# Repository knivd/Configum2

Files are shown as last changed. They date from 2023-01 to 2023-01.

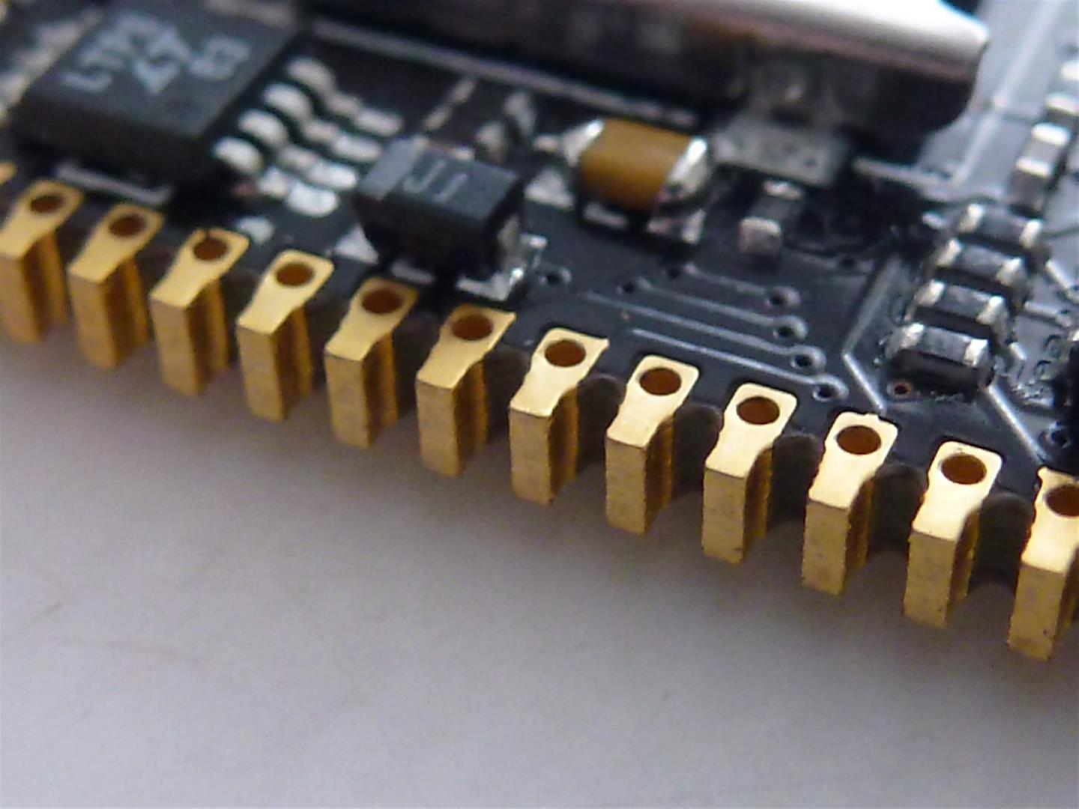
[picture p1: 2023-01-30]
hardware/Pin Finishing.JPG

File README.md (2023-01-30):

# Configum2
Embedded FPGA module in PLCC84 format

This tiny 30x30mm module fits into standard PLCC84 socket and offers:
Artix-7 FPGA, 64Mb configuration flash, 1Gb DDR3, 16Gb eMMC, ESP32 dual-core controller, 64Mb external firmware flash, USB host, 4-channel motor controller, 24MHz oscillator, dual power supply that provides 1.8V and 3.3V to external circuit with over 3A budget, on-board debug LEDs, differential ADC, up to 61 external I/O ports.
FPGA and ESP32 share most of the external pins and can work in parallel.
Configum-2 is ideal for ultra-dense high-end boards for robotics, AI, industrial, wearables, etc.

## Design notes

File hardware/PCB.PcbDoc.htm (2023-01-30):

Reporting Options

# File in Previous Format

Date | : | 31/12/2021
Time | : | 15:15:40
Filename | : | K:\Work\Past\Configum-2\hardware\PCB.PcbDoc

Version | Warning

This file was generated by an earlier version of the software

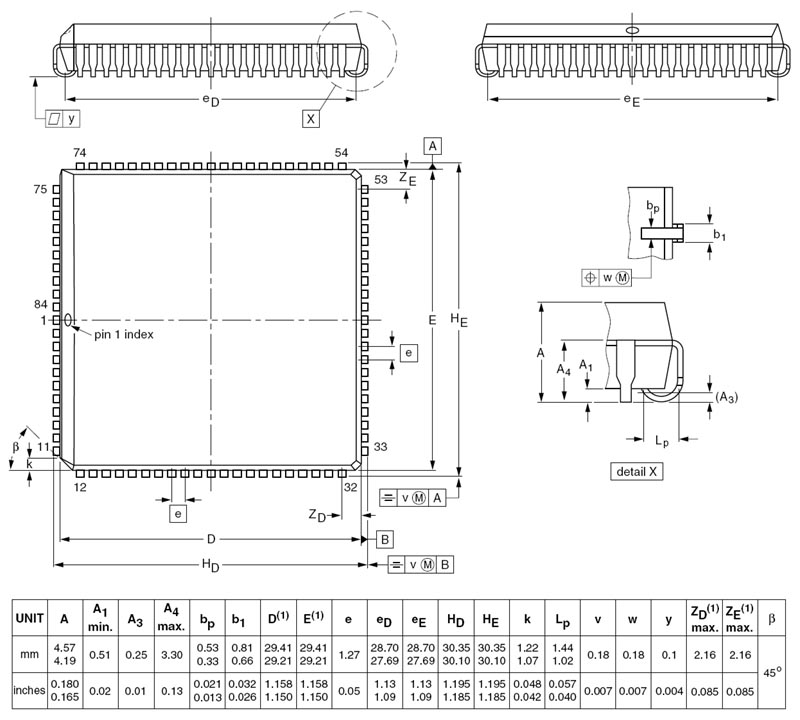
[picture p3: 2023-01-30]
docs/PLCC84.jpg

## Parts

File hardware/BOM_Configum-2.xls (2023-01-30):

Comment | Pattern | Quantity | Components | Vendor | Order Code | Vendor | Order Code | Vendor | Order Code | Description / Minimum Specification
1u | _0201 | 62 | C1, C2, C3, C4, C5, C6, C7, C8, C9, C10, C11, C12, C13, C14, C15, C16, C17, C18, C19, C20, C21, C22, C23, C24, C25, C26, C27, C28, C29, C30, C31, C32, C33, C34, C35, C36, C37, C38, C39, C40, C42, C43, C44, C45, C46, C47, C48, C49, C52, C56, C59, C62, C63, C74, C80, C102, C103, C104, C105, C107, C108, C109 | Any |  |  |  |  |  | Ceramic capacitor, X-type, 10%, 6V or higher
270p | _0201 | 2 | C100, C101 | Any |  |  |  |  |  | Ceramic capacitor, C0G/NP0, 5%, 6V or higher
100n | _0201 | 30 | C41, C50, C58, C61, C64, C65, C66, C67, C69, C70, C71, C72, C73, C75, C77, C78, C81, C83, C84, C86, C88, C89, C91, C92, C93, C94, C98, C106, C110, C112 | Any |  |  |  |  |  | Ceramic capacitor, X-type, 10%, 6V or higher
33n | _0201 | 1 | C51 | Any |  |  |  |  |  | Ceramic capacitor, X-type, 10%, 6V or higher
22u | _0805_CAP | 3 | C53, C54, C111 | Any |  |  |  |  |  | Ceramic capacitor, X-type, 10%, 16V or higher
47u | _0805_CAP | 4 | C55, C60, C68, C90 | Any |  |  |  |  |  | Ceramic capacitor, X-type, 10%, 6V or higher
2u2 | _0201 | 2 | C57, C99 | Any |  |  |  |  |  | Ceramic capacitor, X-type, 10%, 6V or higher
10n | _0201 | 3 | C76, C79, C95 | Any |  |  |  |  |  | Ceramic capacitor, X-type, 10%, 6V or higher
2p4 | _0201 | 1 | C82 | Any |  |  |  |  |  | Ceramic capacitor, C0G/NP0, 5%, 6V or higher
3n | _0201 | 1 | C85 | Any |  |  |  |  |  | Ceramic capacitor, X-type, 10%, 6V or higher
3p9 | _0201 | 1 | C87 | Any |  |  |  |  |  | Ceramic capacitor, C0G/NP0, 5%, 6V or higher
10u | _0603 | 2 | C96, C97 | Any |  |  |  |  |  | Ceramic capacitor, X-type, 10%, 6V or higher
2n7 | _0201 | 1 | L5 | Any |  |  |  |  |  | Inductor
1k | _0201 | 5 | R1, R3, R4, R7, R53 | Any |  |  |  |  |  | Resistor, 1%
12k | _0201 | 1 | R11 | Any |  |  |  |  |  | Resistor, 1%
27k | _0201 | 1 | R13 | Any |  |  |  |  |  | Resistor, 1%
90k9 | _0201 | 1 | R14 | Any |  |  |  |  |  | Resistor, 1%
30k1 | _0201 | 1 | R16 | Any |  |  |  |  |  | Resistor, 1%
47k5 | _0201 | 1 | R17 | Any |  |  |  |  |  | Resistor, 1%
20k | _0201 | 3 | R18, R33, R55 | Any |  |  |  |  |  | Resistor, 1%
240R | _0201 | 3 | R19, R20, R22 | Any |  |  |  |  |  | Resistor, 1%
4k7 | _0201 | 7 | R2, R5, R10, R12, R15, R30, R52 | Any |  |  |  |  |  | Resistor, 1%
13k3 | _0201 | 1 | R21 | Any |  |  |  |  |  | Resistor, 1%
47R | _0201 | 27 | R23, R24, R25, R26, R27, R28, R29, R31, R32, R34, R35, R36, R37, R38, R39, R40, R41, R42, R43, R44, R45, R46, R47, R48, R49, R50, R54 | Any |  |  |  |  |  | Resistor, 1%
330R | _0201 | 1 | R6 | Any |  |  |  |  |  | Resistor, 1%
2k4 | _0201 | 1 | R8 | Any |  |  |  |  |  | Resistor, 1%
24R9 | _0201 | 1 | R9 | Any |  |  |  |  |  | Resistor, 1%
DNF | _0201 | 1 | R51 |  |  |  |  |  |  | Resistor, 1%
60R@100MHz | _0201 | 4 | L1, L2, L3, L4 | Aliexpress | 32761245784 | Mouser | 963-BK0603HM600-T | Digikey | 535-12206-1-ND | Inductor
0402R | _0402+ | 1 | LED1 | Aliexpress | 32404466579 | Mouser | 604-APHHS1005SURCK | Digikey | 1516-1217-1-ND | Light Emitting Diode
0402Y | _0402+ | 1 | LED2 | Aliexpress | 32688253887 | Mouser | 604-APHHS1005SYCK | Digikey | 1516-1219-1-ND | Light Emitting Diode
0402G | _0402+ | 1 | LED3 | Aliexpress | 32688370228 | Mouser | 604-APHHS1005CGCK | Digikey | 1516-1216-1-ND | Light Emitting Diode
0402B | _0402+ | 1 | LED4 | Aliexpress | 32403229689 | Mouser | 604-APHHS1005QBCD | Digikey | 1516-1215-1-ND | Light Emitting Diode
XC7A100T-2CSG324C | CSG324 | 1 | U1 | Aliexpress | 32735014145 | Avnet | XC7A100T-2CSG324I | Digikey | 122-1881-ND | Artix-7 FPGA, 210 User I/Os, 0 GTP, 324-Ball BGA, Speed Grade 2, Commercial Grade, Pb-Free
LV8411GR | QFN40P300X300X80_HS-25L | 1 | U11 | Aliexpress | 32575151815 | Mouser | 863-LV8411GR-TE-L-E | Digikey | 869-1285-1-ND | 4-channel single chip motor driver IC
IS25LQ032B-JTLA | SON80P300X60_HS-9L | 2 | U2, U10 | Arrow | MX25L3233FZBI-08G-TR | Arrow | N25Q032A13EF440F | Vertical | N25Q032A13EF440F | Standard 8-pin SPI flash memory
DSC1033DI2-024.0000 | Osc 25x20 (4) | 1 | U3 | Vertical | DSC1033DI2-024.0000 | Mouser | 579-1033DI20240000 | Digikey | DSC1033DI2-024.0000-ND | 32kHz –100MHz CMEMS Oscillator
MIC94093YMT | DFN65P120x120-4 | 2 | U4, U12 | Aliexpress | 32565684921 | Mouser | 998-MIC94093YMTTR | Digikey | 576-3491-1-ND | High-side load switch for consumer applications
ADS7041IRUG | X2QFN50P150X150-8 | 1 | U5 | Aliexpress | 32400654595 | Mouser | 595-ADS7041IRUGR | Digikey | 296-38606-1-ND | Ultra-Low Power, Ultra-Small Size, 10-Bit, 1-MSPS, SAR ADC
USB3300-EZK | QFN50P500X500-32V5N | 1 | U6 | Aliexpress | 32639284916 | Mouser | 886-USB3300-EZK | Digikey | USB3300-EZK-CT-ND | Hi-Speed USB Host, Device or OTG PHY with ULPI Low Pin Interface
AS4C512M16D3L-12BCN | BGA96C80P9X16_900X1400X120 | 1 | U7 | Aliexpress | 32761447879 | Mouser | 913-512M16D3L12BCN | Digikey | 1450-1271-ND | DDR3L RAM 8Gb (512Mx16)
ESP32-D0WDQ6 | QFN40P600X600X90-49N-S470 | 1 | U8 |  |  |  |  |  |  | WiFi, BT4.2, 2xCPU integrated solution
eMMC-153 | BGA153C50P14X14_1150X1300X90 | 1 | U9 | Aliexpress | 32367008543 | Mouser | 757-THGBMHG6C1LBAIL | Digikey | THGBMHG6C1LBAIL-ND | eMMC memory
LTM4643EV#PBF | LGA77C127P7X11_900X1500X182 | 1 | UM1 | Linear | LTM4643EV#PBF |  |  |  |  | Ultrathin Quad Module Regulator with Configurable 3A Output Array

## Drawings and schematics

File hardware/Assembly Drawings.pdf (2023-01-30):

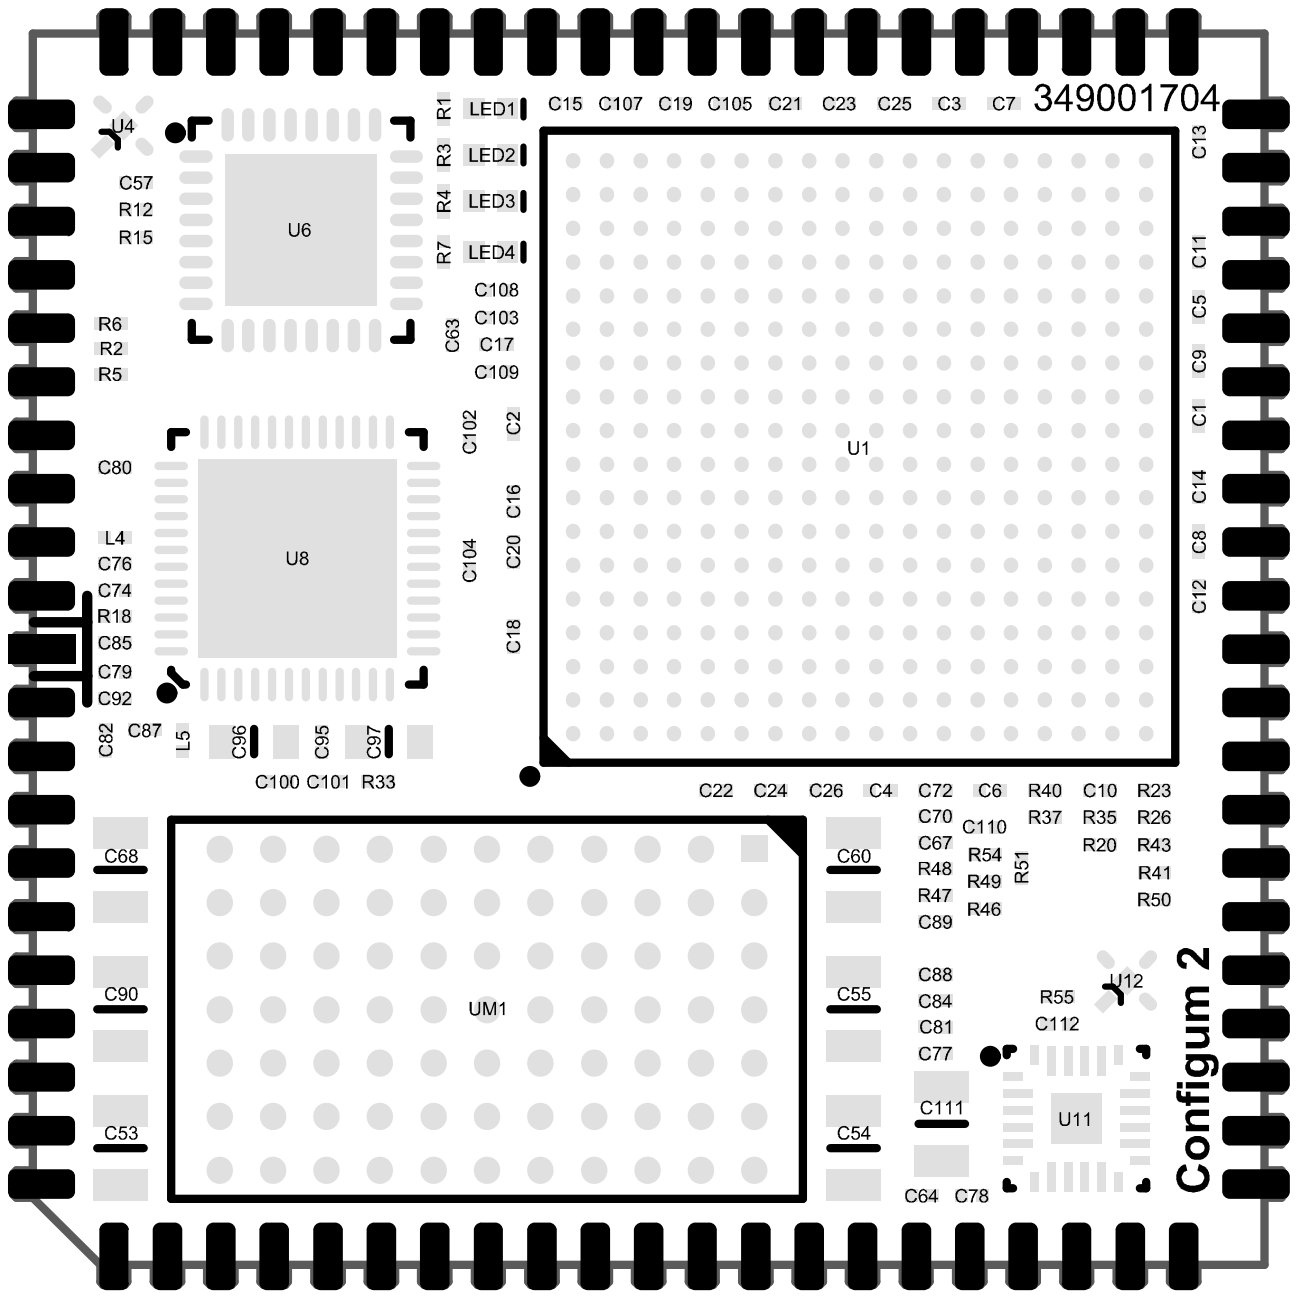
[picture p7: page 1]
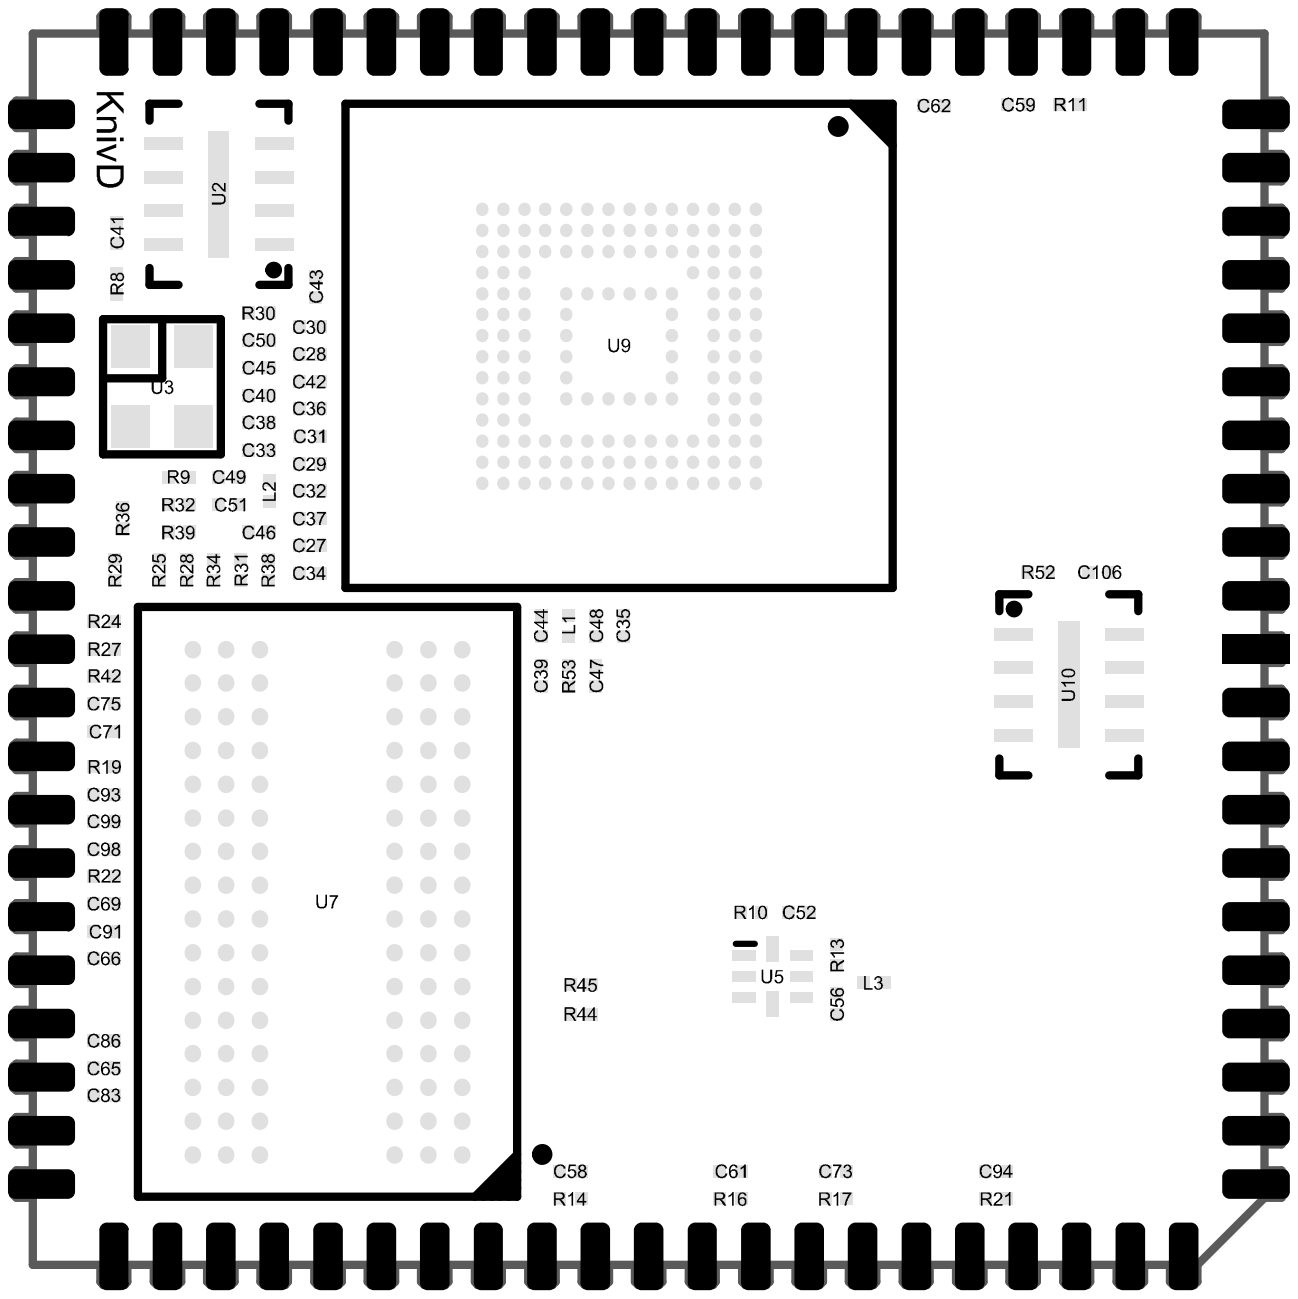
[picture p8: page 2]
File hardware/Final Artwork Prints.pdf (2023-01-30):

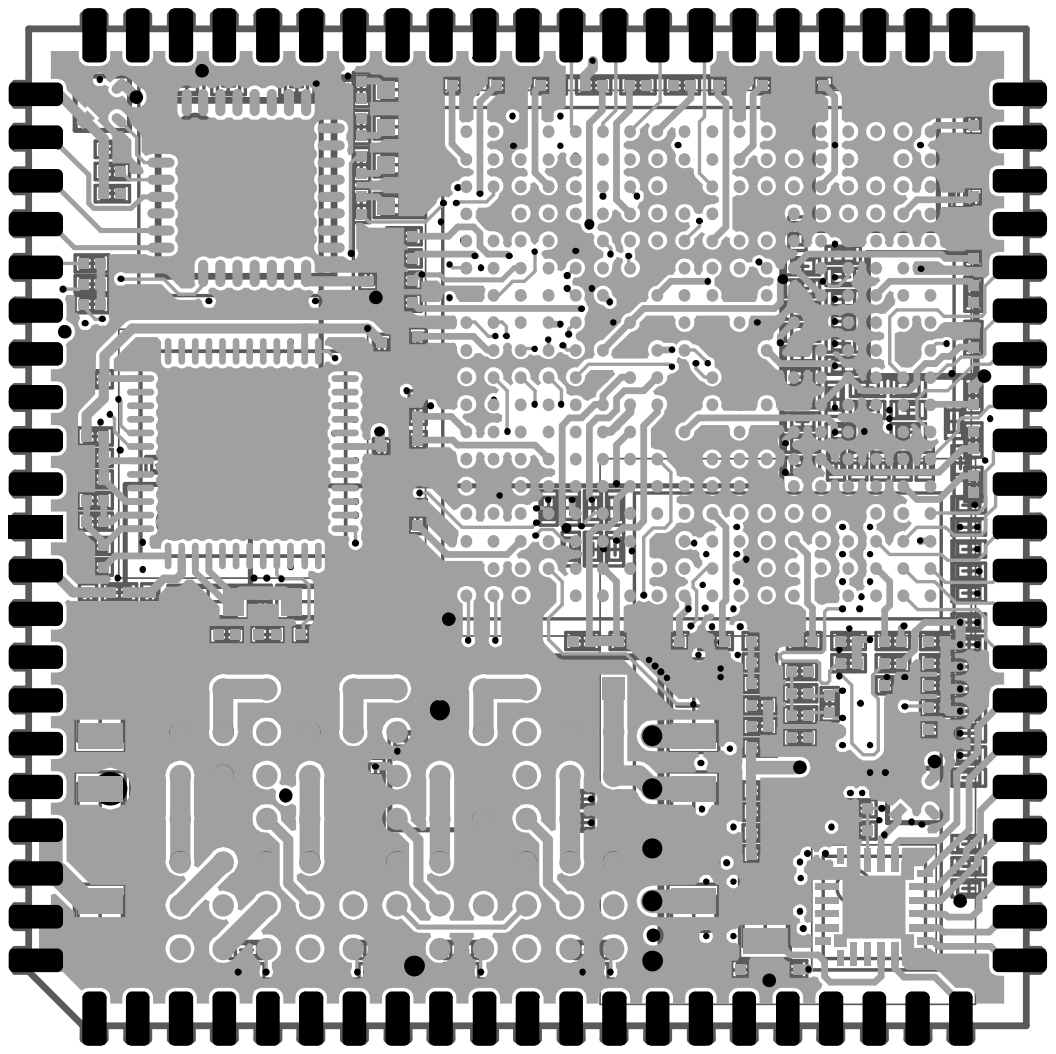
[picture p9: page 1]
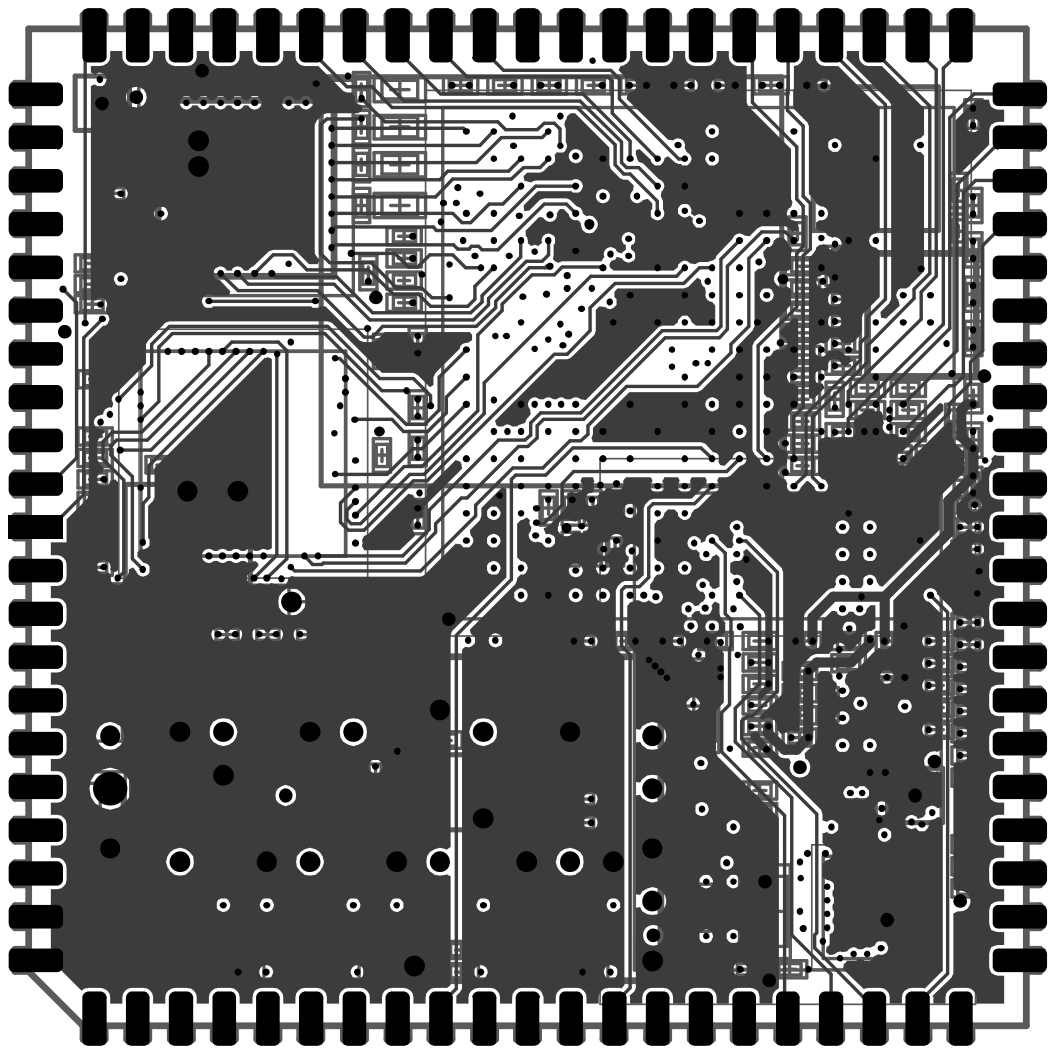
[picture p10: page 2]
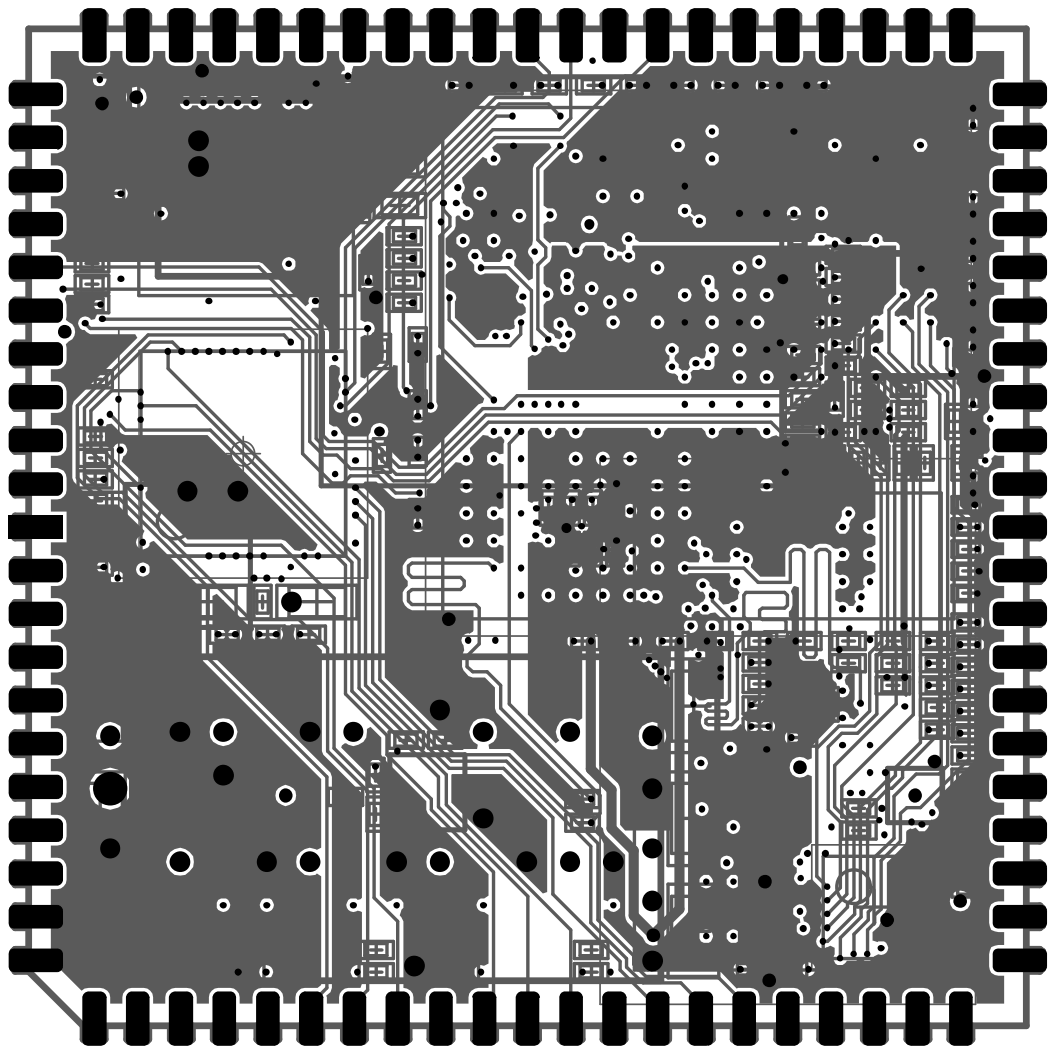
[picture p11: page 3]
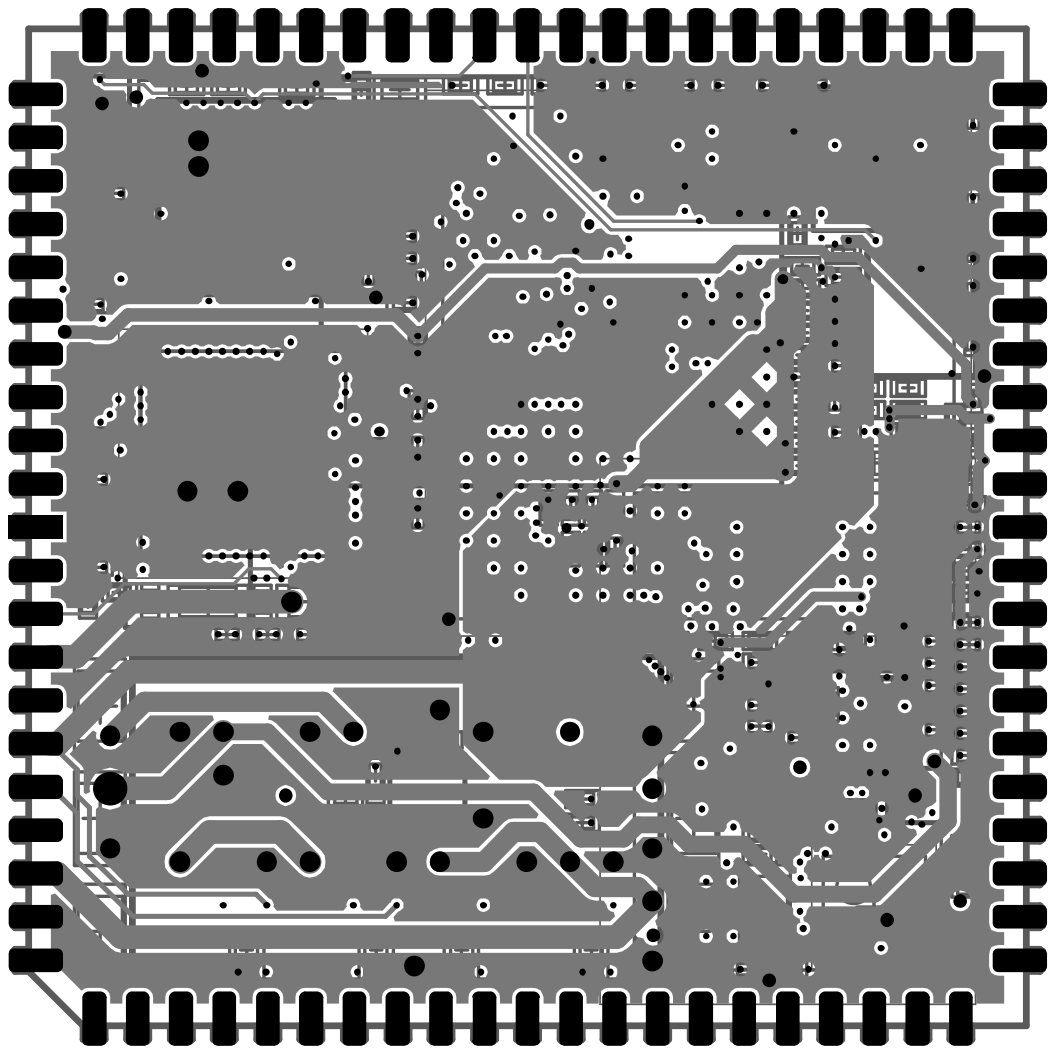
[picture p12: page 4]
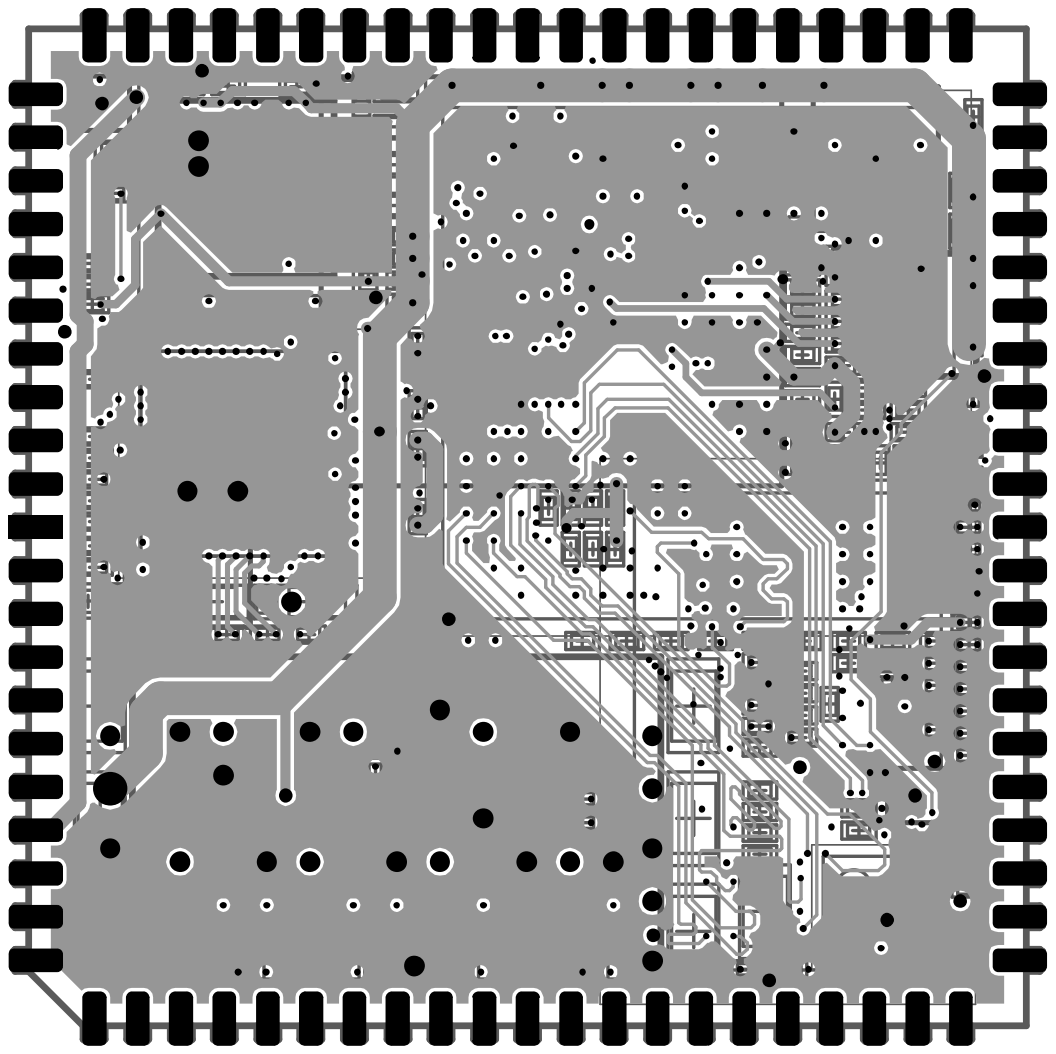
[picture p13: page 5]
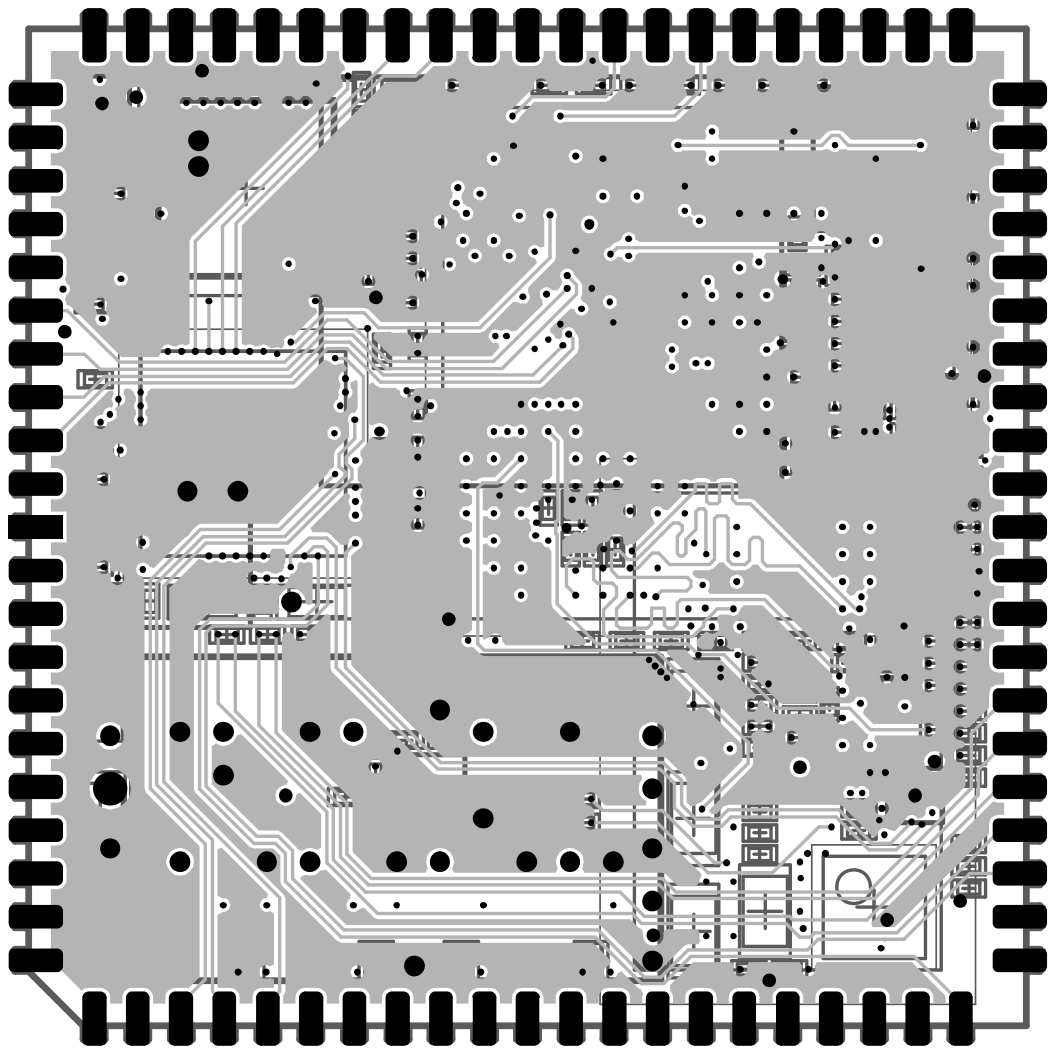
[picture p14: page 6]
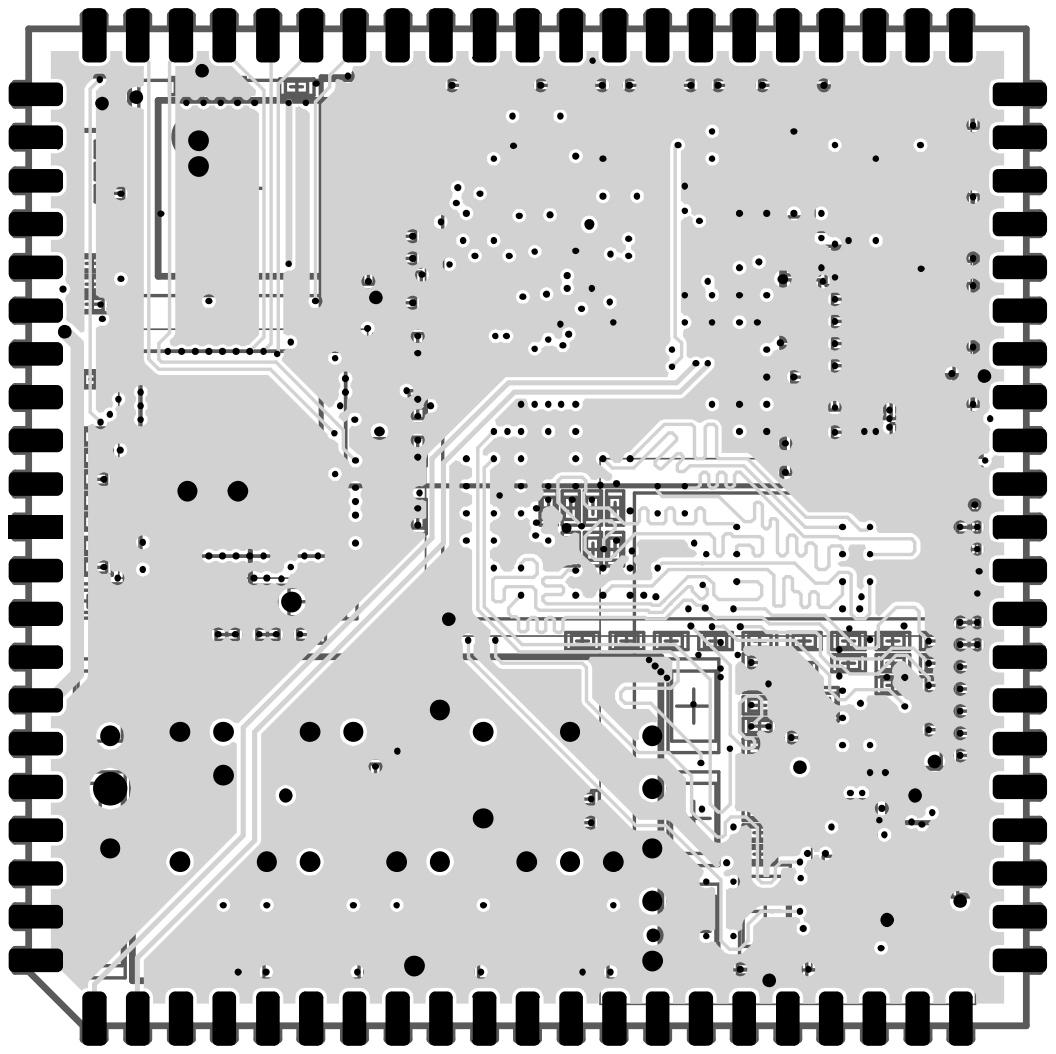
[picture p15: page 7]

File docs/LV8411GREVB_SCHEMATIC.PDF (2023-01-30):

# Schematic for the LV8411GREVB Evaluation Board

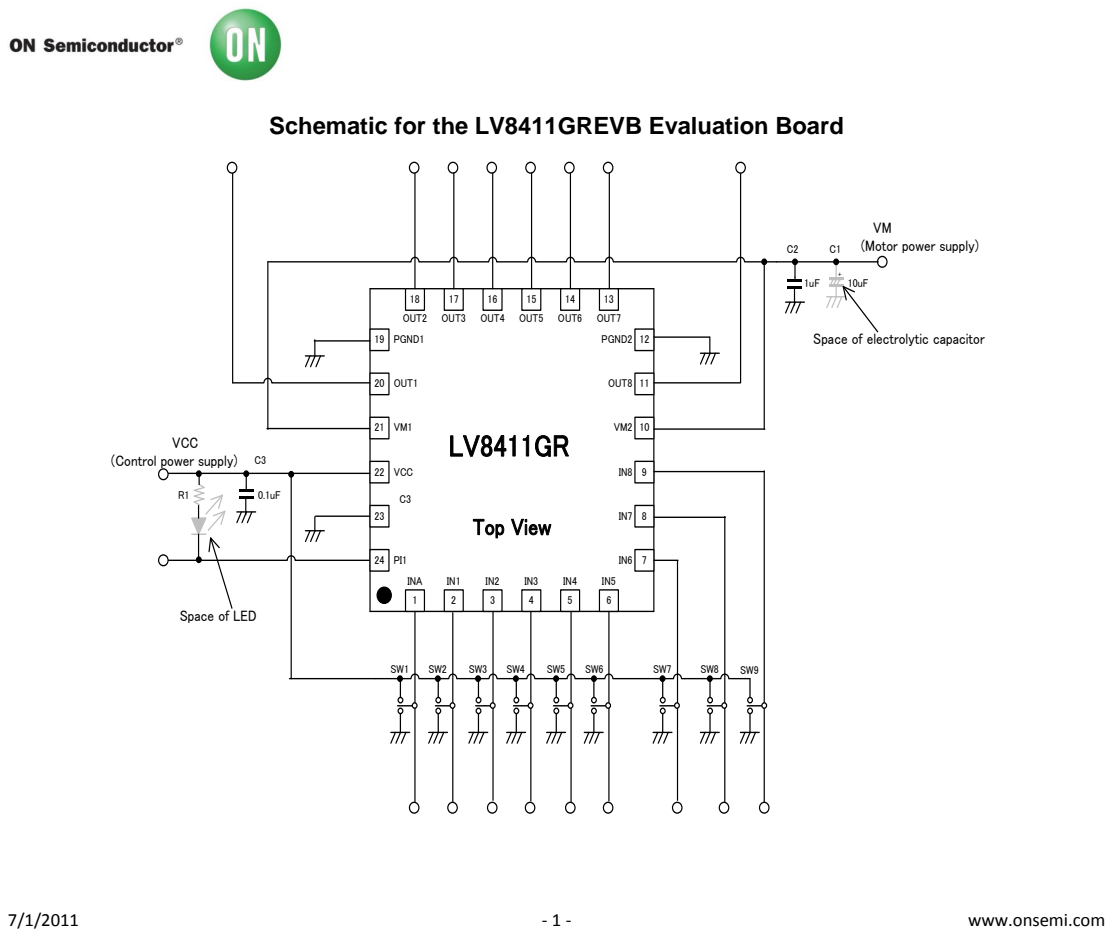
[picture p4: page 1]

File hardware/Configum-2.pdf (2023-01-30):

# 1 nINIT 23456789

# DXN_0 L9 U1F

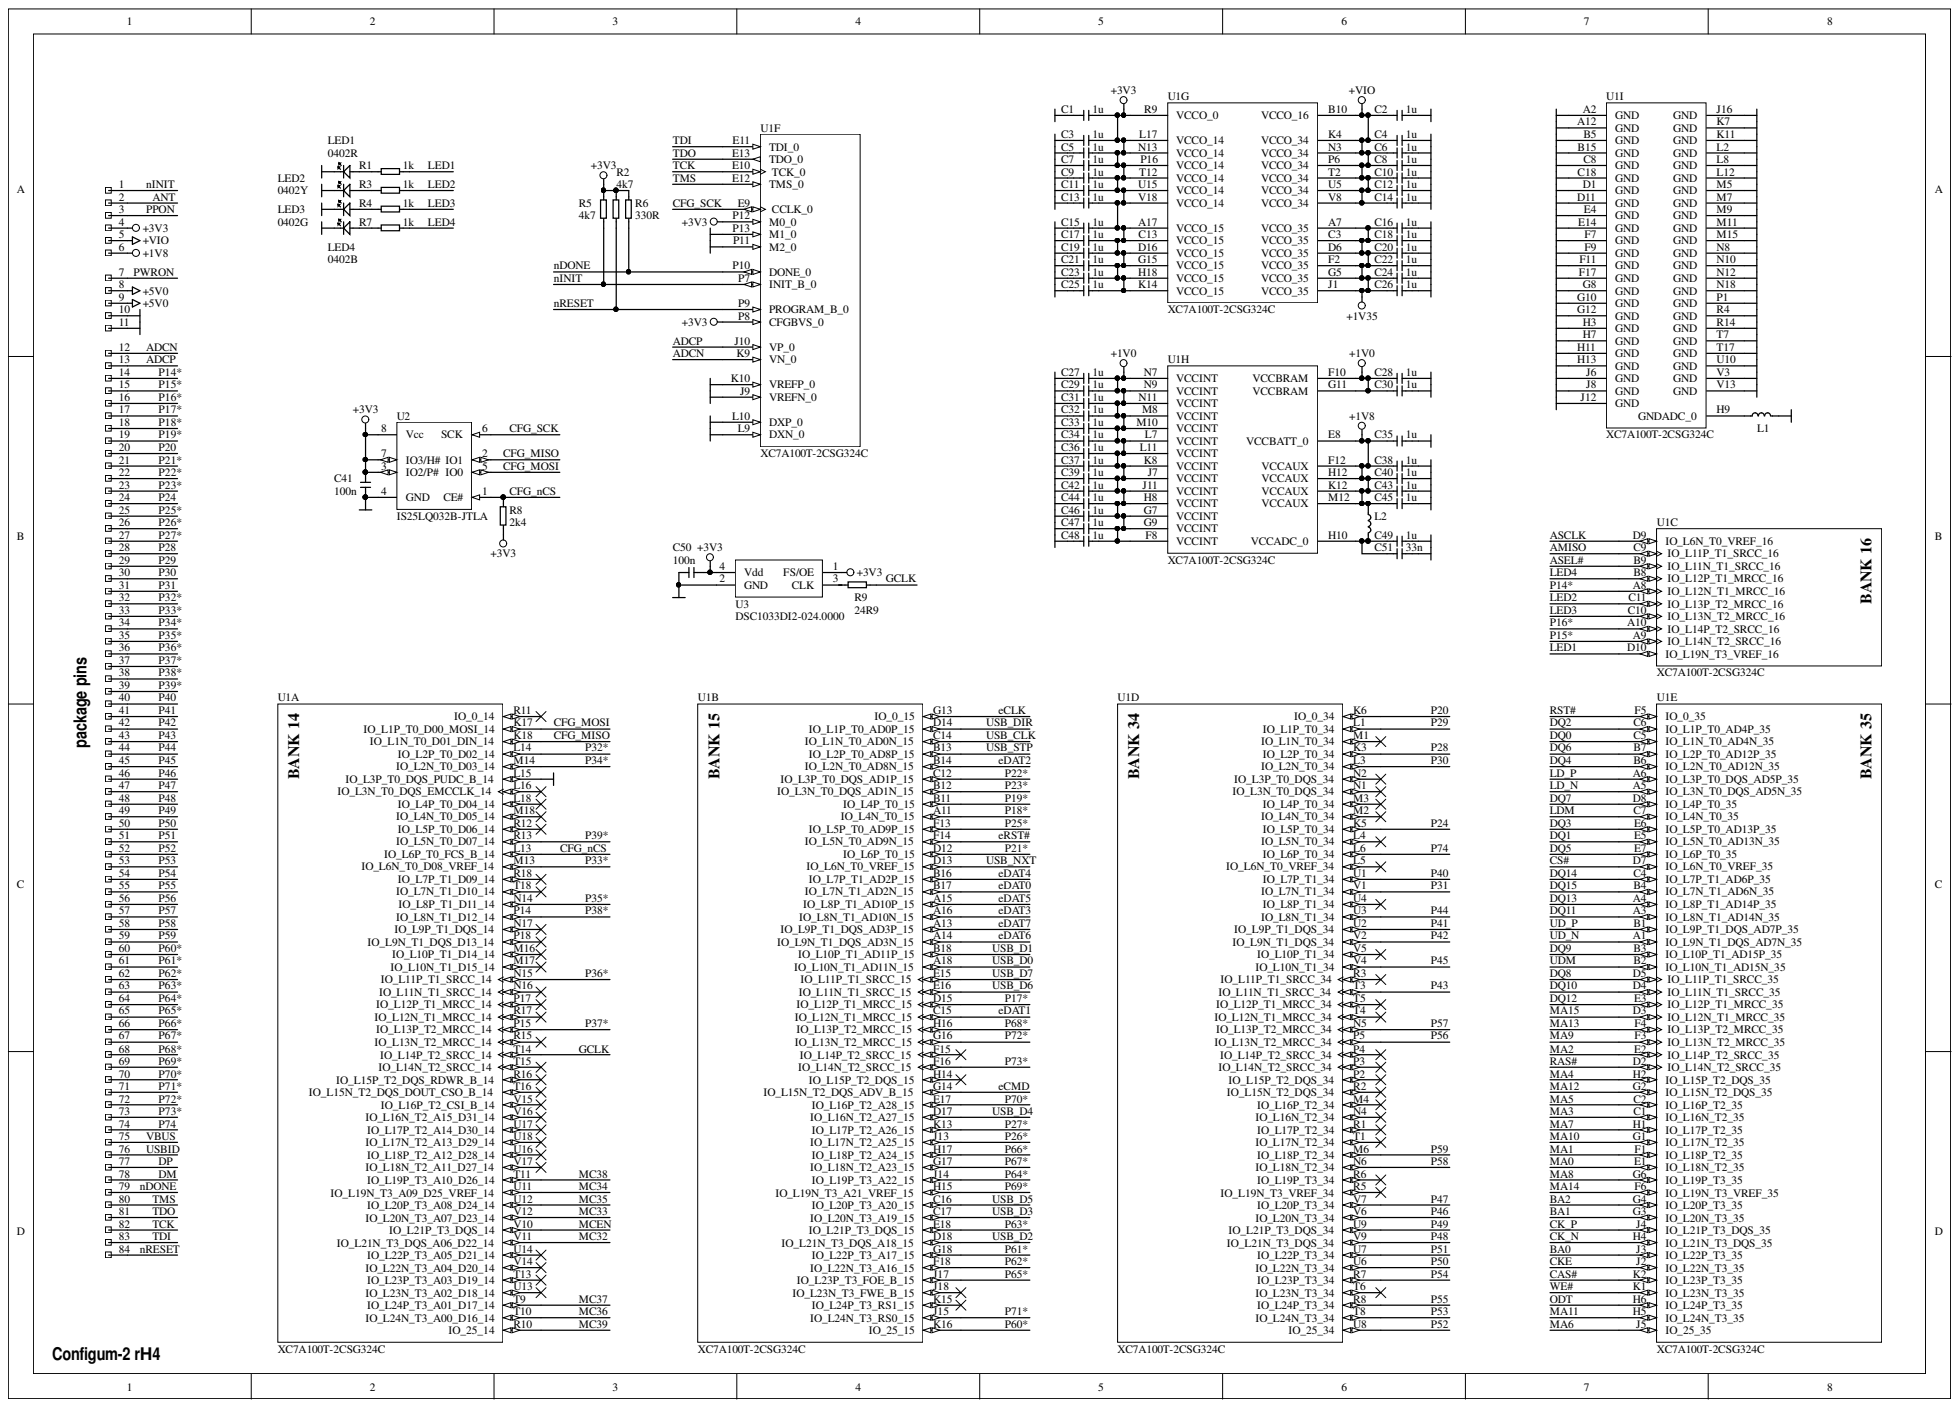
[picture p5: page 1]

## Voltage output sequencing: 1V0 -> 1V8 -> 1V35/3V3

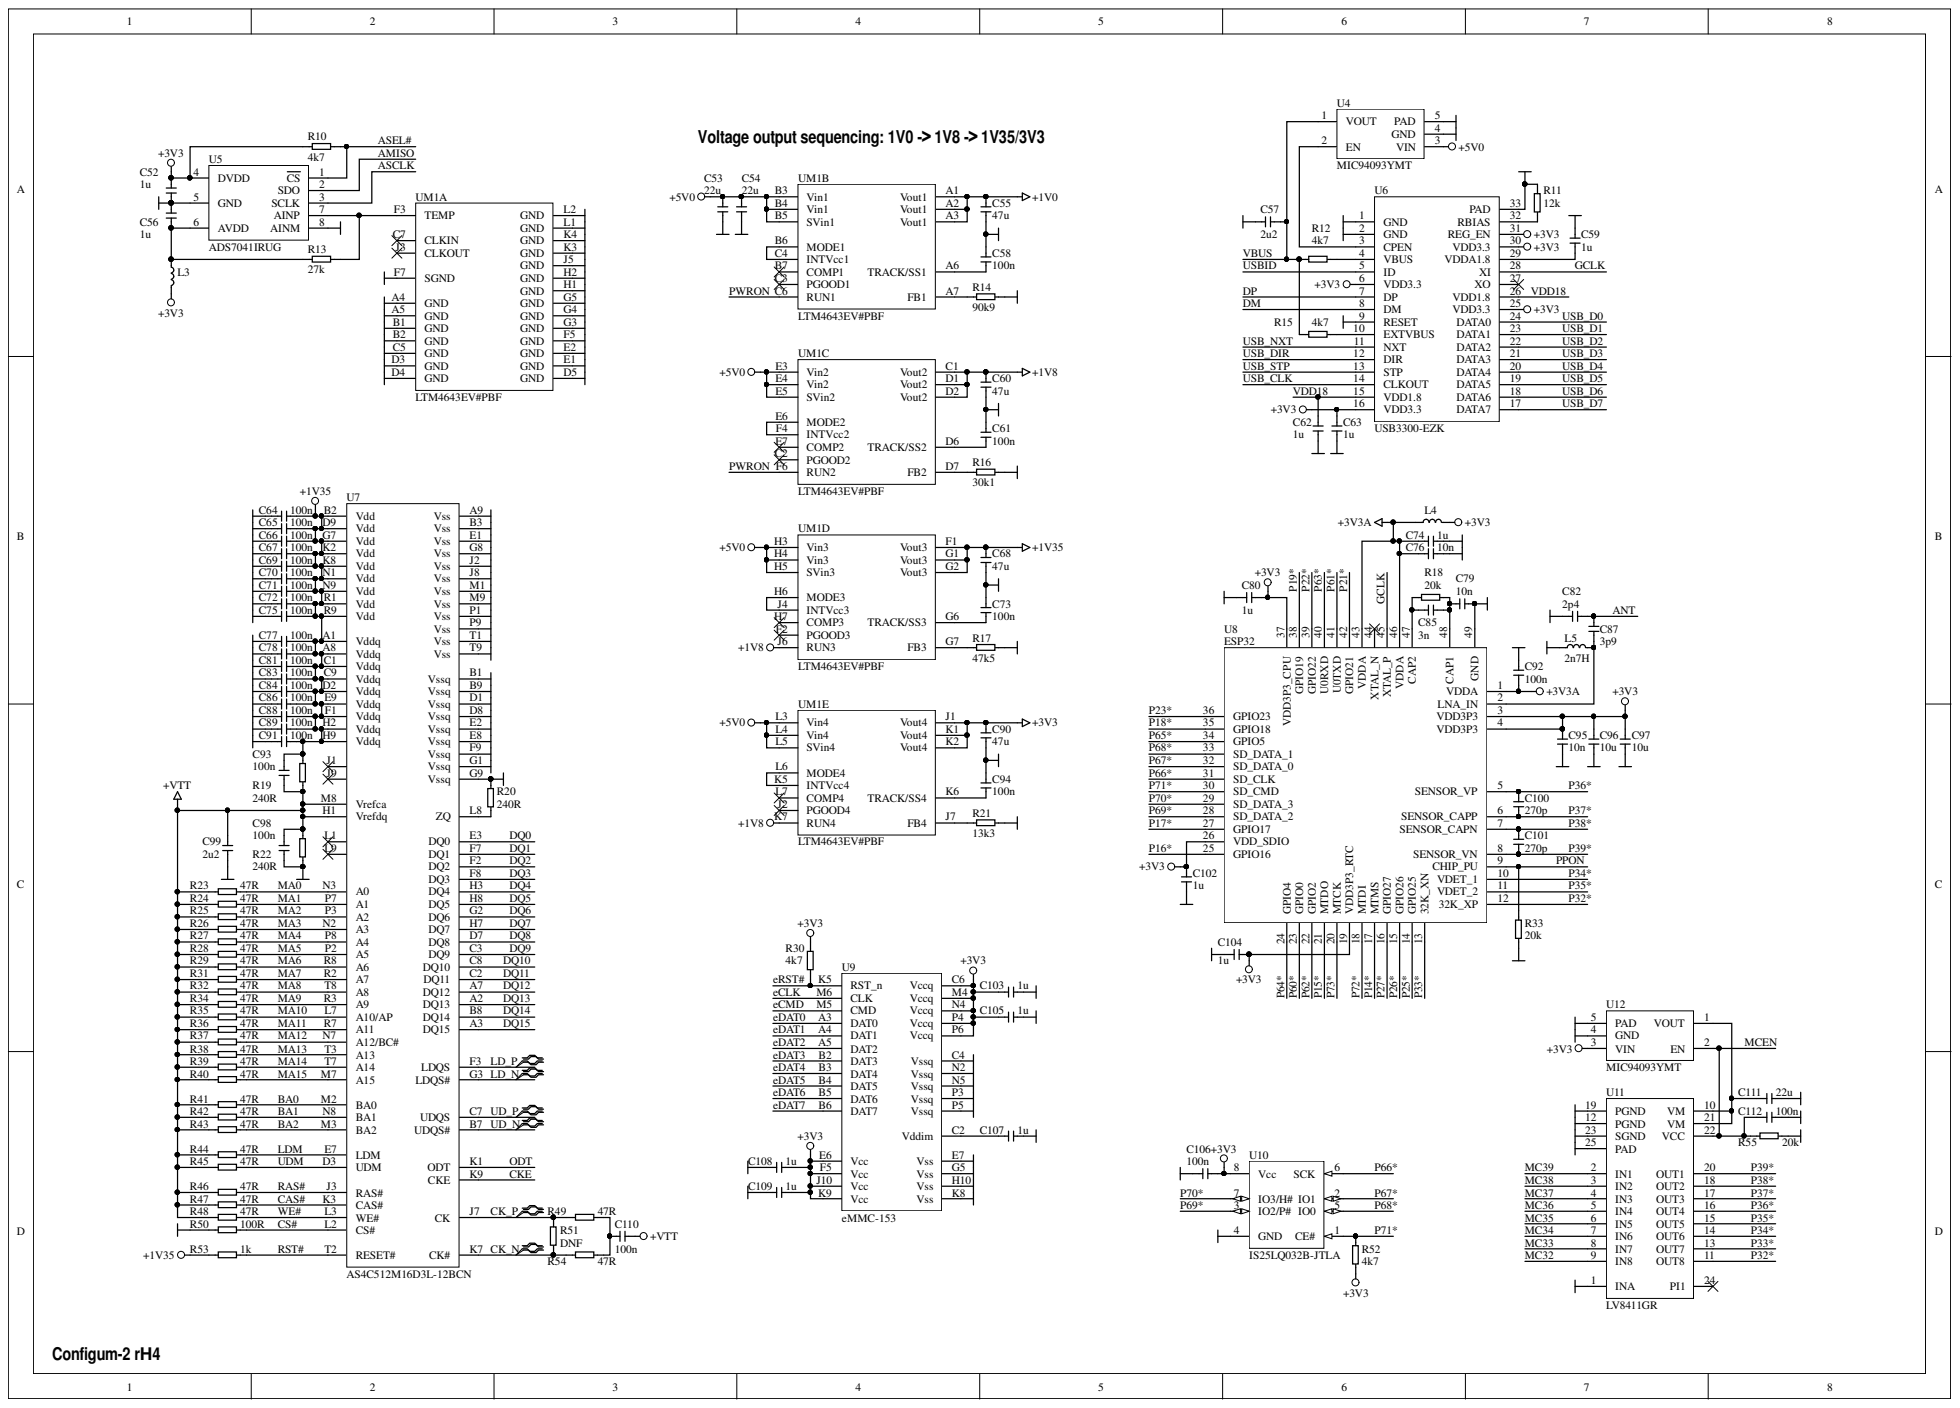
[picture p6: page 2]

32K_XN 13 GPIO25 14 GPIO26 15 GPIO27 16 MTMS 17 MTDI 18 VDD3P3_RTC 19 MTCK 20 MTDO 21 GPIO2 22 GPIO0 23 GPIO4 24
